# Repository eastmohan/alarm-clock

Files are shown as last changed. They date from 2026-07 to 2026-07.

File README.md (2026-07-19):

# alarm-clock

This is an ESP32-C3 Mini based alarm clock. It uses a piezo buzzer for noise and a TFT ILI9341 Touchscreen LCD to show time. There are currently two pages - one for an alarm and one for the time. In the future, there will be a weather page, a weather widget for the home page, a timer, and a stopwatch. The alarm clock features 3 buttons on top. Two control time for alarm set (increase/decrease the hour or minute). The middle key is used to switch pages and switch from editing the hour to minute, etc. Left and right button will be able to turn off the alarm, while the middle button will snooze.






There is a sliding door in the back to access components and assemble the clock:


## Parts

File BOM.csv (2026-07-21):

Item | Source | Qty | Price each | Total component price | Link | Current sale price (total)
2.8" ILI9341 LCD | Amazon | 1 | $11.99 | $11.99 | https://a.co/d/0cWZKgKU | $11.99
ESP32 C3 Super mini | AliExpress | 1 | $4.06 | $4.06 | https://www.aliexpress.us/item/3256812255799117.html?curPageLogUid=N7XyvsNFzGEr | $2.56
Passive Piezo Buzzer | AliExpress | 1 | $1.18 | $1.18 | https://www.aliexpress.us/item/3256806074013807.html?curPageLogUid=2QIpXXeL6XJw | $1.16
Wire (different colors) | AliExpress | 3 | $1.99 | $5.97 | https://www.aliexpress.us/item/3256805135541457.html?curPageLogUid=YwMVvGEUE9ad | $5.97
Perfboard | AliExpress | 1 | $3.70 | $3.70 | https://www.aliexpress.us/item/3256805949797804.html?curPageLogUid=wLBeh7xtf5a6 | $2.20
Key switches | AliExpress | 1 | $6.26 | $6.26 | https://www.aliexpress.us/item/3256812117552846.html?curPageLogUid=pIkArG3cBoKZ | $4.76
Keycaps | AliExpress | 1 | $3.89 | $3.89 | https://www.aliexpress.us/item/3256810359094598.html?curPageLogUid=m39cQvKpkHrn | $2.39
Heat shrink | AliExpress | 1 | $7.09 | $7.09 | https://www.aliexpress.us/item/3256811806875013.html?curPageLogUid=icbivwKsduoh | $1.99
100 ohm resistor (100R) | AliExpress | 1 | $0.92 | $0.92 | https://www.aliexpress.us/item/3256802303553096.html?curPageLogUid=TO37sp2RzT7c | $0.90
USB-C to USB-A cable | Amazon | 1 | $5.99 | $5.99 | https://a.co/d/08SZNABU | $5.99
 |  |  | TOTAL: | $51.05 | TOTAL (after sales): | $39.91

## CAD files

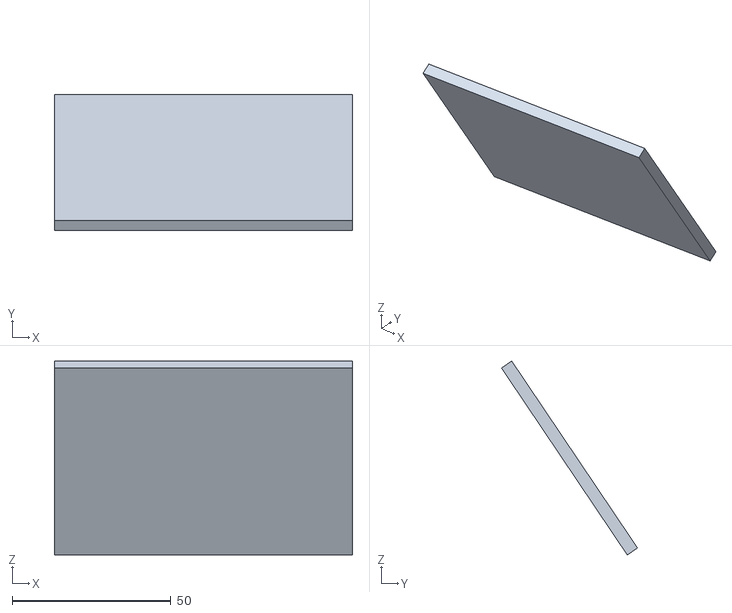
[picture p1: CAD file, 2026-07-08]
CAD/door.stl
94.0 x 42.9 x 61.2

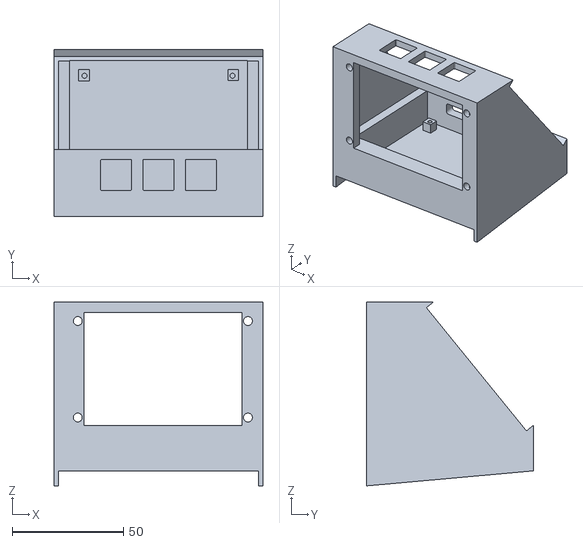
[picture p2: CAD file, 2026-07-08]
CAD/case.stl
94.0 x 75.0 x 82.7

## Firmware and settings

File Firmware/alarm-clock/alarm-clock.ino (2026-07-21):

#include <SPI.h>
#include <TFT_eSPI.h>
#include <WiFi.h>
#include <time.h>

#define LEFT_BTN_PIN 2
#define MIDDLE_BTN_PIN 4
#define RIGHT_BTN_PIN 5
#define BUZZER_PIN 3

const char* WIFI_SSID = "wifi name";
const char* WIFI_PASSWORD = "wifi password";

const char* NTP_SERVER = "pool.ntp.org";
const char* TZ_INFO = "EST5EDT,M3.2.0,M11.1.0";

TFT_eSPI tft = TFT_eSPI();

#define COL_BG TFT_BLACK
#define COL_TEXT TFT_WHITE
#define COL_DIM 0x7BEF
#define COL_ACCENT TFT_CYAN
#define COL_ALARM TFT_ORANGE
#define COL_OK TFT_GREEN
#define COL_OFF TFT_RED

struct Button {
  uint8_t pin;
  bool lastState;
  bool stableState;
  unsigned long lastChange;
  bool pressedEvent;
};

Button btnLeft = {LEFT_BTN_PIN, HIGH, HIGH, 0, false};
Button btnMiddle = {MIDDLE_BTN_PIN, HIGH, HIGH, 0, false};
Button btnRight = {RIGHT_BTN_PIN, HIGH, HIGH, 0, false};

const unsigned long DEBOUNCE_MS = 30;

unsigned long lastMiddlePressTime = 0;
const unsigned long DOUBLE_PRESS_WINDOW_MS = 400;
bool middleDoublePressEvent = false;

enum Screen {
  SCR_HOME,
  SCR_ALARM_HOME,
  SCR_ALARM_SET_HOUR,
  SCR_ALARM_SET_MIN,
  SCR_ALARM_SET_TOGGLE,
  SCR_TIMER_HOME,
  SCR_TIMER_SET_HOUR,
  SCR_TIMER_SET_MIN,
  SCR_TIMER_RUNNING,
  SCR_STOPWATCH
};

Screen currentScreen = SCR_HOME;
Screen lastDrawnScreen = (Screen)-1;
bool screenDirty = true;

int alarmHour = 7;
int alarmMinute = 0;
bool alarmEnabled = false;
bool alarmRinging = false;

int timerSetHour = 0;
int timerSetMinute = 5;
bool timerRunning = false;
unsigned long timerEndMillis = 0;
long timerRemainingSeconds = 0;
bool timerRinging = false;

bool stopwatchRunning = false;
unsigned long stopwatchStartMillis = 0;
unsigned long stopwatchAccumMillis = 0;

void buzzShort() {
  tone(BUZZER_PIN, 2000, 80);
}

void buzzBeepBeep() {
  tone(BUZZER_PIN, 1500, 60);
}

unsigned long lastRingToggle = 0;
bool ringToneOn = false;
void serviceRinging(bool &ringingFlag) {
  if (!ringingFlag) return;
  unsigned long now = millis();
  if (now - lastRingToggle > 400) {
    lastRingToggle = now;
    ringToneOn = !ringToneOn;
    if (ringToneOn) tone(BUZZER_PIN, 2500);
    else noTone(BUZZER_PIN);
  }
}

void stopRinging(bool &ringingFlag) {
  ringingFlag = false;
  noTone(BUZZER_PIN);
}

void updateButton(Button &b) {
  bool reading = digitalRead(b.pin);
  b.pressedEvent = false;

  if (reading != b.lastState) {
    b.lastChange = millis();
  }

  if ((millis() - b.lastChange) > DEBOUNCE_MS) {
    if (reading != b.stableState) {
      b.stableState = reading;
      if (b.stableState == LOW) {
        b.pressedEvent = true;
      }
    }
  }
  b.lastState = reading;
}

void readButtons() {
  updateButton(btnLeft);
  updateButton(btnMiddle);
  updateButton(btnRight);

  middleDoublePressEvent = false;
  if (btnMiddle.pressedEvent) {
    unsigned long now = millis();
    if (now - lastMiddlePressTime <= DOUBLE_PRESS_WINDOW_MS) {
      middleDoublePressEvent = true;
    }
    lastMiddlePressTime = now;
  }
}

bool getTimeNow(struct tm &timeinfo) {
  return getLocalTime(&timeinfo, 5);
}

String formatTime12(int h, int m, bool withAmPm = true) {
  int displayHour = h % 12;
  if (displayHour == 0) displayHour = 12;
  char buf[16];
  if (withAmPm) {
    snprintf(buf, sizeof(buf), "%d:%02d %s", displayHour, m, (h >= 12) ? "PM" : "AM");
  } else {
    snprintf(buf, sizeof(buf), "%d:%02d", displayHour, m);
  }
  return String(buf);
}

String formatDate(struct tm &t) {
  static const char* wdays[] = {"Sun","Mon","Tue","Wed","Thu","Fri","Sat"};
  static const char* mons[] = {"Jan","Feb","Mar","Apr","May","Jun","Jul","Aug","Sep","Oct","Nov","Dec"};
  char buf[24];
  snprintf(buf, sizeof(buf), "%s, %s %d", wdays[t.tm_wday], mons[t.tm_mon], t.tm_mday);
  return String(buf);
}

void clearScreen() {
  tft.fillScreen(COL_BG);
}

void drawFooterHint(const char* left, const char* mid, const char* right) {
  tft.setTextDatum(BL_DATUM);
  tft.setTextColor(COL_DIM, COL_BG);
  tft.setTextSize(1);
  tft.drawString(left, 6, tft.height() - 4, 2);
  tft.setTextDatum(BC_DATUM);
  tft.drawString(mid, tft.width() / 2, tft.height() - 4, 2);
  tft.setTextDatum(BR_DATUM);
  tft.drawString(right, tft.width() - 6, tft.height() - 4, 2);
}

void drawHome(bool fullRedraw) {
  struct tm t;
  bool haveTime = getTimeNow(t);

  if (fullRedraw) {
    clearScreen();
    drawFooterHint("", "", "Next >");
  }

  tft.setTextDatum(MC_DATUM);
  tft.setTextColor(COL_TEXT, COL_BG);
  String timeStr = haveTime ? formatTime12(t.tm_hour, t.tm_min) : "--:--";
  tft.fillRect(0, 70, tft.width(), 60, COL_BG);
  tft.drawString(timeStr, tft.width() / 2, 100, 7);

  tft.setTextDatum(TL_DATUM);
  tft.setTextColor(COL_DIM, COL_BG);
  tft.fillRect(0, 150, 150, 20, COL_BG);
  String dateStr = haveTime ? formatDate(t) : "--- -- --";
  tft.drawString(dateStr, 10, 150, 2);

  tft.fillRect(150, 145, tft.width() - 150, 30, COL_BG);
  if (alarmEnabled) {
    tft.setTextDatum(TR_DATUM);
    tft.setTextColor(COL_ALARM, COL_BG);
    String a = "@ " + formatTime12(alarmHour, alarmMinute);
    tft.drawString(a, tft.width() - 10, 150, 2);
  }
}

void drawTimeEditor(const char* title, int hourVal, int minVal, bool editingHour) {
  clearScreen();
  tft.setTextDatum(TC_DATUM);
  tft.setTextColor(COL_ACCENT, COL_BG);
  tft.drawString(title, tft.width() / 2, 20, 4);

  tft.setTextDatum(MC_DATUM);
  char hbuf[3], mbuf[3];
  snprintf(hbuf, sizeof(hbuf), "%02d", hourVal);
  snprintf(mbuf, sizeof(mbuf), "%02d", minVal);

  int cx = tft.width() / 2;
  int cy = 110;

  tft.setTextColor(editingHour ? COL_OK : COL_DIM, COL_BG);
  tft.drawString(hbuf, cx - 45, cy, 7);

  tft.setTextColor(COL_DIM, COL_BG);
  tft.drawString(":", cx, cy, 7);

  tft.setTextColor(!editingHour ? COL_OK : COL_DIM, COL_BG);
  tft.drawString(mbuf, cx + 45, cy, 7);

  drawFooterHint("< Dec", "Next v", "Inc >");
}

void drawToggleScreen(const char* title, bool val) {
  clearScreen();
  tft.setTextDatum(TC_DATUM);
  tft.setTextColor(COL_ACCENT, COL_BG);
  tft.drawString(title, tft.width() / 2, 20, 4);

  tft.setTextDatum(MC_DATUM);
  tft.setTextColor(val ? COL_OK : COL_OFF, COL_BG);
  tft.drawString(val ? "ON" : "OFF", tft.width() / 2, 110, 7);

  drawFooterHint("< Toggle", "Save v", "Toggle >");
}

void drawAlarmHome(bool fullRedraw) {
  if (fullRedraw) clearScreen();
  tft.setTextDatum(TC_DATUM);
  tft.setTextColor(COL_ACCENT, COL_BG);
  tft.fillRect(0, 15, tft.width(), 30, COL_BG);
  tft.drawString("Alarm", tft.width() / 2, 20, 4);

  tft.setTextDatum(MC_DATUM);
  tft.fillRect(0, 70, tft.width(), 90, COL_BG);
  tft.setTextColor(alarmEnabled ? COL_OK : COL_DIM, COL_BG);
  tft.drawString(formatTime12(alarmHour, alarmMinute), tft.width() / 2, 100, 7);

  tft.setTextDatum(TC_DATUM);
  tft.setTextColor(alarmEnabled ? COL_OK : COL_OFF, COL_BG);
  tft.drawString(alarmEnabled ? "ENABLED" : "DISABLED", tft.width() / 2, 150, 2);

  drawFooterHint("< Home", "Edit", "Timer >");
}

void drawTimerHome(bool fullRedraw) {
  if (fullRedraw) clearScreen();
  tft.setTextDatum(TC_DATUM);
  tft.setTextColor(COL_ACCENT, COL_BG);
  tft.fillRect(0, 15, tft.width(), 30, COL_BG);
  tft.drawString("Timer", tft.width() / 2, 20, 4);

  tft.setTextDatum(MC_DATUM);
  tft.fillRect(0, 70, tft.width(), 90, COL_BG);
  char buf[9];
  snprintf(buf, sizeof(buf), "%02d:%02d", timerSetHour, timerSetMinute);
  tft.setTextColor(COL_DIM, COL_BG);
  tft.drawString(buf, tft.width() / 2, 100, 7);

  tft.setTextDatum(TC_DATUM);
  tft.setTextColor(COL_DIM, COL_BG);
  tft.drawString("Not running", tft.width() / 2, 150, 2);

  drawFooterHint("< Alarm", "Edit", "Stopwatch >");
}

void drawTimerRunning(bool fullRedraw) {
  if (fullRedraw) clearScreen();
  tft.setTextDatum(TC_DATUM);
  tft.setTextColor(COL_ACCENT, COL_BG);
  tft.fillRect(0, 15, tft.width(), 30, COL_BG);
  tft.drawString("Timer Running", tft.width() / 2, 20, 4);

  long secs = timerRemainingSeconds;
  if (secs < 0) secs = 0;
  int hh = secs / 3600;
  int mm = (secs % 3600) / 60;
  int ss = secs % 60;
  char buf[12];
  snprintf(buf, sizeof(buf), "%02d:%02d:%02d", hh, mm, ss);

  tft.setTextDatum(MC_DATUM);
  tft.fillRect(0, 70, tft.width(), 60, COL_BG);
  tft.setTextColor(timerRinging ? COL_OFF : COL_OK, COL_BG);
  tft.drawString(buf, tft.width() / 2, 100, 6);

  drawFooterHint("< Alarm", "", "Stopwatch >");
}

void drawStopwatch(bool fullRedraw) {
  if (fullRedraw) clearScreen();
  tft.setTextDatum(TC_DATUM);
  tft.setTextColor(COL_ACCENT, COL_BG);
  tft.fillRect(0, 15, tft.width(), 30, COL_BG);
  tft.drawString("Stopwatch", tft.width() / 2, 20, 4);

  unsigned long elapsed = stopwatchAccumMillis;
  if (stopwatchRunning) {
    elapsed += millis() - stopwatchStartMillis;
  }
  unsigned long totalSec = elapsed / 1000;
  int mm = (totalSec / 60) % 60;
  int ss = totalSec % 60;
  int cs = (elapsed % 1000) / 10;

  char buf[12];
  snprintf(buf, sizeof(buf), "%02d:%02d.%02d", mm, ss, cs);

  tft.setTextDatum(MC_DATUM);
  tft.fillRect(0, 70, tft.width(), 60, COL_BG);
  tft.setTextColor(stopwatchRunning ? COL_OK : COL_TEXT, COL_BG);
  tft.drawString(buf, tft.width() / 2, 100, 6);

  tft.setTextDatum(TC_DATUM);
  tft.setTextColor(COL_DIM, COL_BG);
  tft.fillRect(0, 150, tft.width(), 20, COL_BG);
  tft.drawString(stopwatchRunning ? "Running" : "Paused", tft.width() / 2, 150, 2);

  drawFooterHint("< Timer", "Start/Pause", "Home >");
}

void goToScreen(Screen s) {
  currentScreen = s;
  screenDirty = true;
}

void handleHomeScreen() {
  if (btnRight.pressedEvent) {
    goToScreen(SCR_ALARM_HOME);
  }
  if (alarmRinging && (btnLeft.pressedEvent || btnMiddle.pressedEvent || btnRight.pressedEvent)) {
    stopRinging(alarmRinging);
  }
}

void handleAlarmHome() {
  if (alarmRinging && (btnLeft.pressedEvent || btnMiddle.pressedEvent || btnRight.pressedEvent)) {
    stopRinging(alarmRinging);
    return;
  }
  if (btnLeft.pressedEvent) goToScreen(SCR_HOME);
  else if (btnRight.pressedEvent) goToScreen(SCR_TIMER_HOME);
  else if (btnMiddle.pressedEvent) goToScreen(SCR_ALARM_SET_HOUR);
}

void handleAlarmSetHour() {
  if (btnRight.pressedEvent) { alarmHour = (alarmHour + 1) % 24; screenDirty = true; buzzShort(); }
  if (btnLeft.pressedEvent)  { alarmHour = (alarmHour + 23) % 24; screenDirty = true; buzzShort(); }
  if (btnMiddle.pressedEvent) goToScreen(SCR_ALARM_SET_MIN);
}

void handleAlarmSetMin() {
  if (btnRight.pressedEvent) { alarmMinute = (alarmMinute + 1) % 60; screenDirty = true; buzzShort(); }
  if (btnLeft.pressedEvent)  { alarmMinute = (alarmMinute + 59) % 60; screenDirty = true; buzzShort(); }
  if (btnMiddle.pressedEvent) goToScreen(SCR_ALARM_SET_TOGGLE);
}

void handleAlarmSetToggle() {
  if (btnRight.pressedEvent || btnLeft.pressedEvent) { alarmEnabled = !alarmEnabled; screenDirty = true; buzzShort(); }
  if (btnMiddle.pressedEvent) goToScreen(SCR_ALARM_HOME);
}

void handleTimerHome() {
  if (timerRinging && (btnLeft.pressedEvent || btnMiddle.pressedEvent || btnRight.pressedEvent)) {
    stopRinging(timerRinging);
    return;
  }
  if (btnLeft.pressedEvent) goToScreen(SCR_ALARM_HOME);
  else if (btnRight.pressedEvent) goToScreen(SCR_STOPWATCH);
  else if (btnMiddle.pressedEvent) goToScreen(SCR_TIMER_SET_HOUR);
}

void handleTimerSetHour() {
  if (btnRight.pressedEvent) { timerSetHour = (timerSetHour + 1) % 24; screenDirty = true; buzzShort(); }
  if (btnLeft.pressedEvent)  { timerSetHour = (timerSetHour + 23) % 24; screenDirty = true; buzzShort(); }
  if (btnMiddle.pressedEvent) goToScreen(SCR_TIMER_SET_MIN);
}

void handleTimerSetMin() {
  if (btnRight.pressedEvent) { timerSetMinute = (timerSetMinute + 1) % 60; screenDirty = true; buzzShort(); }
  if (btnLeft.pressedEvent)  { timerSetMinute = (timerSetMinute + 59) % 60; screenDirty = true; buzzShort(); }
  if (btnMiddle.pressedEvent) {
    long totalSeconds = (long)timerSetHour * 3600 + (long)timerSetMinute * 60;
    if (totalSeconds <= 0) totalSeconds = 60;
    timerRemainingSeconds = totalSeconds;
    timerEndMillis = millis() + totalSeconds * 1000UL;
    timerRunning = true;
    timerRinging = false;
    goToScreen(SCR_TIMER_RUNNING);
  }
}

void handleTimerRunning() {
  if (timerRinging && (btnLeft.pressedEvent || btnMiddle.pressedEvent || btnRight.pressedEvent)) {
    stopRinging(timerRinging);
    timerRunning = false;
    goToScreen(SCR_TIMER_HOME);
    return;
  }
  if (btnLeft.pressedEvent) goToScreen(SCR_ALARM_HOME);
  else if (btnRight.pressedEvent) goToScreen(SCR_STOPWATCH);
}

void handleStopwatch() {
  if (btnLeft.pressedEvent) { goToScreen(SCR_TIMER_HOME); return; }
  if (btnRight.pressedEvent) { goToScreen(SCR_HOME); return; }

  if (middleDoublePressEvent) {
    stopwatchRunning = false;
    stopwatchAccumMillis = 0;
    screenDirty = true;
    buzzBeepBeep();
  } else if (btnMiddle.pressedEvent) {
    if (stopwatchRunning) {
      stopwatchAccumMillis += millis() - stopwatchStartMillis;
      stopwatchRunning = false;
    } else {
      stopwatchStartMillis = millis();
      stopwatchRunning = true;
    }
    screenDirty = true;
    buzzShort();
  }
}

int lastCheckedMinute = -1;

void checkAlarmTrigger() {
  if (!alarmEnabled || alarmRinging) return;
  struct tm t;
  if (!getTimeNow(t)) return;
  if (t.tm_min != lastCheckedMinute) {
    lastCheckedMinute = t.tm_min;
    if (t.tm_hour == alarmHour && t.tm_min == alarmMinute) {
      alarmRinging = true;
    }
  }
}

void updateTimerCountdown() {
  if (!timerRunning) return;
  long remainingMs = (long)(timerEndMillis - millis());
  if (remainingMs <= 0) {
    timerRemainingSeconds = 0;
    if (!timerRinging) {
      timerRinging = true;
    }
  } else {
    timerRemainingSeconds = remainingMs / 1000;
  }
  if (currentScreen == SCR_TIMER_RUNNING) screenDirty = true;
}

void setup() {
  Serial.begin(115200);

  pinMode(LEFT_BTN_PIN, INPUT_PULLUP);
  pinMode(MIDDLE_BTN_PIN, INPUT_PULLUP);
  pinMode(RIGHT_BTN_PIN, INPUT_PULLUP);
  pinMode(BUZZER_PIN, OUTPUT);

  tft.init();
  tft.setRotation(1);
  tft.fillScreen(COL_BG);
  tft.setTextDatum(MC_DATUM);
  tft.setTextColor(COL_TEXT, COL_BG);
  tft.drawString("Connecting WiFi...", tft.width() / 2, tft.height() / 2, 2);

  WiFi.mode(WIFI_STA);
  WiFi.begin(WIFI_SSID, WIFI_PASSWORD);
  unsigned long wifiStart = millis();
  while (WiFi.status() != WL_CONNECTED && millis() - wifiStart < 15000) {
    delay(250);
  }

  if (WiFi.status() == WL_CONNECTED) {
    configTzTime(TZ_INFO, NTP_SERVER);
    struct tm t;
    getLocalTime(&t, 10000);
  } else {
    tft.fillScreen(COL_BG);
    tft.drawString("WiFi failed - check creds", tft.width() / 2, tft.height() / 2, 2);
    delay(1500);
  }

  goToScreen(SCR_HOME);
}

void loop() {
  readButtons();
  checkAlarmTrigger();
  updateTimerCountdown();
  serviceRinging(alarmRinging);
  serviceRinging(timerRinging);

  switch (currentScreen) {
    case SCR_HOME:             handleHomeScreen();     break;
    case SCR_ALARM_HOME:       handleAlarmHome();      break;
    case SCR_ALARM_SET_HOUR:   handleAlarmSetHour();   break;
    case SCR_ALARM_SET_MIN:    handleAlarmSetMin();    break;
    case SCR_ALARM_SET_TOGGLE: handleAlarmSetToggle(); break;
    case SCR_TIMER_HOME:       handleTimerHome();      break;
    case SCR_TIMER_SET_HOUR:   handleTimerSetHour();   break;
    case SCR_TIMER_SET_MIN:    handleTimerSetMin();    break;
    case SCR_TIMER_RUNNING:    handleTimerRunning();   break;
    case SCR_STOPWATCH:        handleStopwatch();      break;
  }

  bool fullRedraw = (currentScreen != lastDrawnScreen);
  if (fullRedraw || screenDirty || currentScreen == SCR_HOME || currentScreen == SCR_STOPWATCH || currentScreen == SCR_TIMER_RUNNING) {
    switch (currentScreen) {
      case SCR_HOME:             drawHome(fullRedraw); break;
      case SCR_ALARM_HOME:       drawAlarmHome(fullRedraw); break;
      case SCR_ALARM_SET_HOUR:   drawTimeEditor("Set Alarm", alarmHour, alarmMinute, true); break;
      case SCR_ALARM_SET_MIN:    drawTimeEditor("Set Alarm", alarmHour, alarmMinute, false); break;
      case SCR_ALARM_SET_TOGGLE: drawToggleScreen("Alarm Enabled?", alarmEnabled); break;
      case SCR_TIMER_HOME:       drawTimerHome(fullRedraw); break;
      case SCR_TIMER_SET_HOUR:   drawTimeEditor("Set Timer", timerSetHour, timerSetMinute, true); break;
      case SCR_TIMER_SET_MIN:    drawTimeEditor("Set Timer", timerSetHour, timerSetMinute, false); break;
      case SCR_TIMER_RUNNING:    drawTimerRunning(fullRedraw); break;
      case SCR_STOPWATCH:        drawStopwatch(fullRedraw); break;
    }
    lastDrawnScreen = currentScreen;
    screenDirty = false;
  }

  delay(10);
}

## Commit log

2026-07-08 added CAD
    [case.stl, door.stl]
2026-07-19 update firmware
    switching to just alarm-clock.ino, new page and button structure as well.
2026-07-21 Replaced alarm-clock.ino with an updated version
    [alarm-clock.ino]
